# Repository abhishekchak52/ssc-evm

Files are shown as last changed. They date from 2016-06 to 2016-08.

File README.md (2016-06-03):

# ssc-evm
The Electronic Voting Machine for the St. Stephen's College Student's Union Society Elections for 2016-2017. With love from the Electronics Society

The basic design of the EVM is based on the Atmel ATmega328 chip which is at the heart of the Arduino UNO.
The final circuit will use only the chip instead of the entire Arduino board. The code is written in the Arduino language.

##TODO
* Make a working prototype using the Arduino UNO.
* Test for bugs.
* Port to a 40 AVR PDIP chip.

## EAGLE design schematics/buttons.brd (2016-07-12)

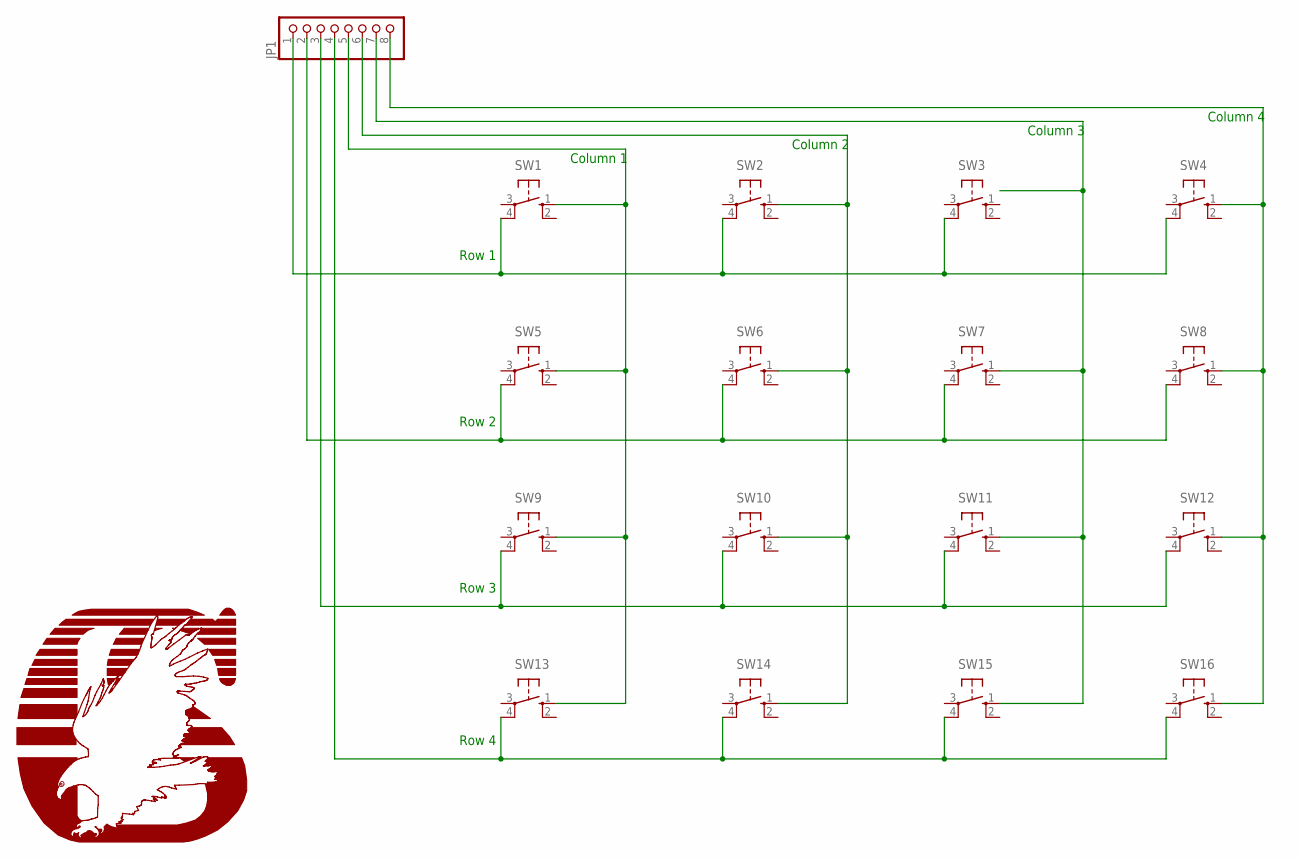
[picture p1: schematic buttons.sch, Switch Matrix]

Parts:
JP1: PINHD-1X8-3.5MM; 1X08-3.5MM
SW1, SW2, SW3, SW4, SW5, SW6, SW7, SW8, SW9, SW10, SW11, SW12, SW13, SW14, SW15, SW16: 10-XX; B3F-10XX

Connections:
unnamed: JP1.1, SW1.4 (P1), SW2.4 (P1), SW3.4 (P1), SW4.4 (P1)
unnamed: JP1.2, SW5.4 (P1), SW6.4 (P1), SW7.4 (P1), SW8.4 (P1)
unnamed: JP1.3, SW9.4 (P1), SW10.4 (P1), SW11.4 (P1), SW12.4 (P1)
unnamed: JP1.4, SW13.4 (P1), SW14.4 (P1), SW15.4 (P1), SW16.4 (P1)
unnamed: JP1.5, SW1.1 (S), SW5.1 (S), SW9.1 (S), SW13.1 (S)
unnamed: JP1.6, SW2.1 (S), SW6.1 (S), SW10.1 (S), SW14.1 (S)
unnamed: JP1.7, SW7.1 (S), SW11.1 (S), SW15.1 (S)
unnamed: JP1.8, SW4.1 (S), SW8.1 (S), SW12.1 (S), SW16.1 (S)

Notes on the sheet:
Row 1
Row 2
Row 3
Row 4
Column 1
Column 2
Column 3
Column 4

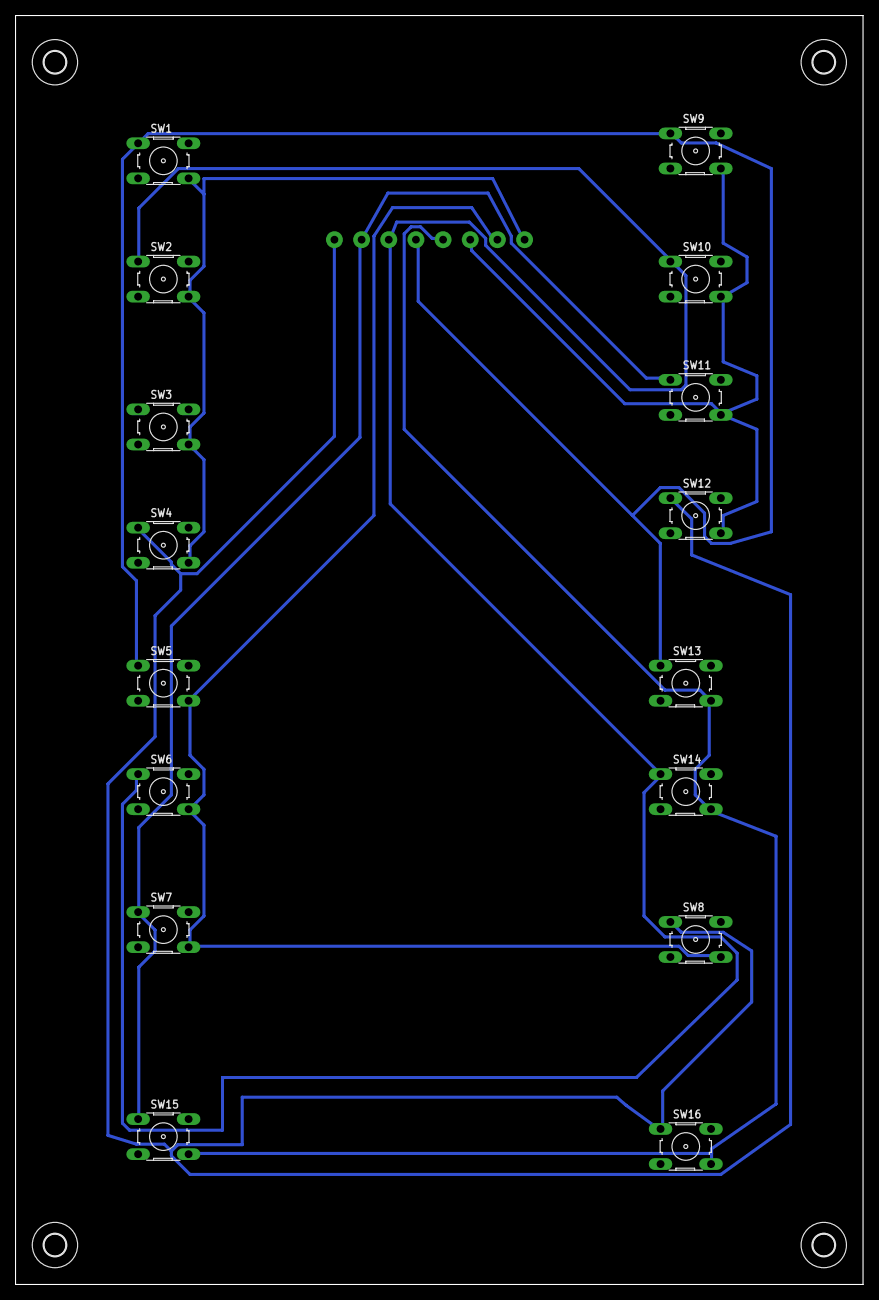
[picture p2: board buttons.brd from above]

Board: 2 copper layers, 109.2 x 163.5 mm, 21 parts (1 on the bottom side), 8 nets.

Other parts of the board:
U$1, U$2, U$3, U$4: 2,8

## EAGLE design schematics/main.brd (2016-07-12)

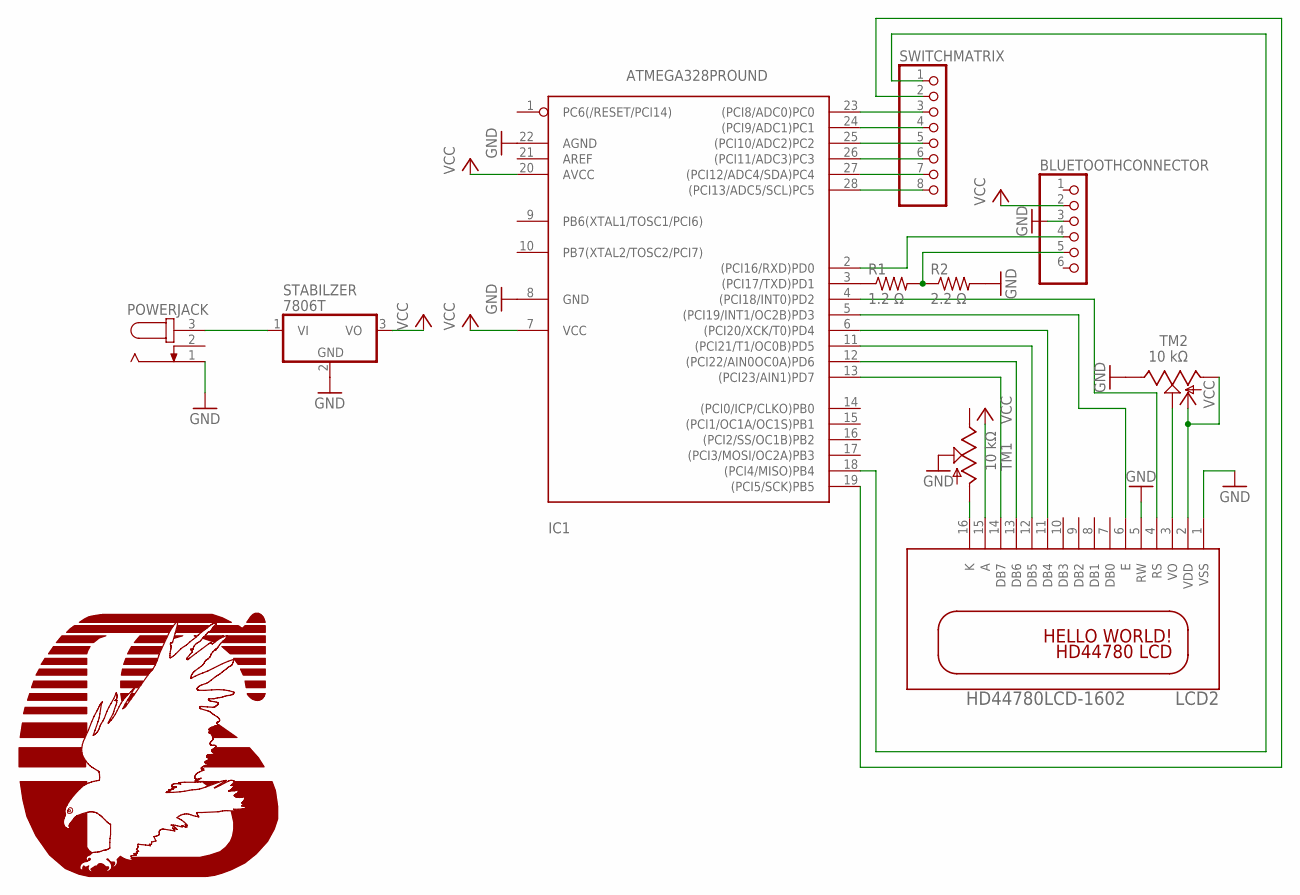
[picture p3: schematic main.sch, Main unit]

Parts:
BLUETOOTHCONNECTOR: PINHD-1X6B; 1X06-BIG
IC1: ATMEGA328PROUND; DIL28-3-ROUND
LCD2: HD44780LCD-1602; LCD1602
POWERJACK: JACK-PLUG0; SPC4077
R1: 1.2 Ω; 0207/10
R2: 2.2 Ω; 0207/10
STABILZER: 7806T; TO220H
SWITCHMATRIX: PINHD-1X8BIG; 1X08-BIG
TM1, TM2: 10 kΩ; 6MM

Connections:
GND: BLUETOOTHCONNECTOR.3, IC1.8 (GND), IC1.22 (AGND), LCD2.1 (VSS), LCD2.5 (RW), POWERJACK.1, R2.2, STABILZER.2 (GND), TM1.S, TM2.E
unnamed: BLUETOOTHCONNECTOR.4, IC1.2 ((PCI16/RXD)PD0)
unnamed: IC1.3 ((PCI17/TXD)PD1), R1.1
unnamed: BLUETOOTHCONNECTOR.5, R1.2, R2.1
unnamed: IC1.4 ((PCI18/INT0)PD2), LCD2.4 (RS)
unnamed: IC1.5 ((PCI19/INT1/OC2B)PD3), LCD2.6 (E)
unnamed: IC1.13 ((PCI23/AIN1)PD7), LCD2.14 (DB7)
unnamed: IC1.12 ((PCI22/AIN0OC0A)PD6), LCD2.13 (DB6)
unnamed: IC1.11 ((PCI21/T1/OC0B)PD5), LCD2.12 (DB5)
unnamed: LCD2.16 (K), TM1.A
unnamed: LCD2.3 (VO), TM2.S
unnamed: IC1.6 ((PCI20/XCK/T0)PD4), LCD2.11 (DB4)
unnamed: IC1.23 ((PCI8/ADC0)PC0), SWITCHMATRIX.3
unnamed: IC1.24 ((PCI9/ADC1)PC1), SWITCHMATRIX.4
unnamed: IC1.25 ((PCI10/ADC2)PC2), SWITCHMATRIX.5
unnamed: IC1.26 ((PCI11/ADC3)PC3), SWITCHMATRIX.6
unnamed: IC1.27 ((PCI12/ADC4/SDA)PC4), SWITCHMATRIX.7
unnamed: IC1.28 ((PCI13/ADC5/SCL)PC5), SWITCHMATRIX.8
unnamed: IC1.18 ((PCI4/MISO)PB4), SWITCHMATRIX.1
unnamed: IC1.19 ((PCI5/SCK)PB5), SWITCHMATRIX.2
unnamed: POWERJACK.3, STABILZER.1 (VI)
VCC: BLUETOOTHCONNECTOR.2, IC1.7 (VCC), IC1.20 (AVCC), LCD2.2 (VDD), LCD2.15 (A), STABILZER.3 (VO), TM2.A

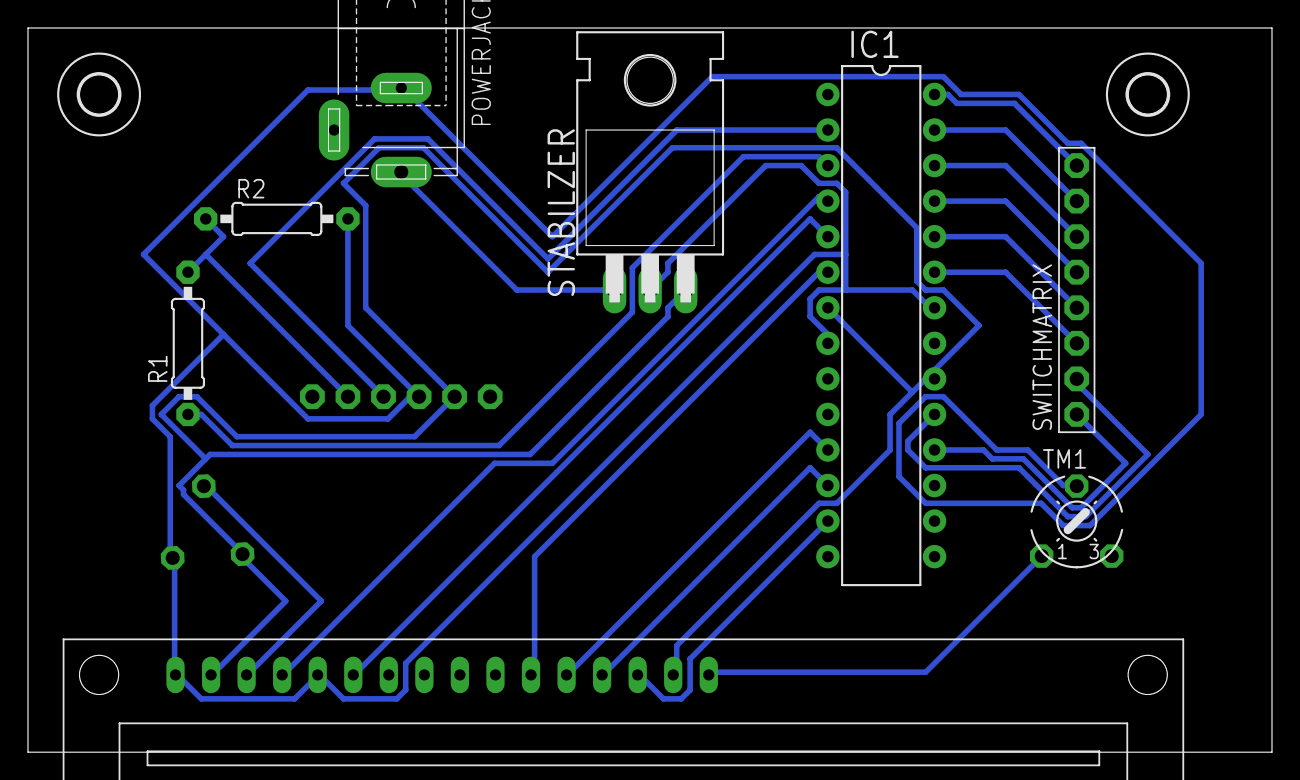
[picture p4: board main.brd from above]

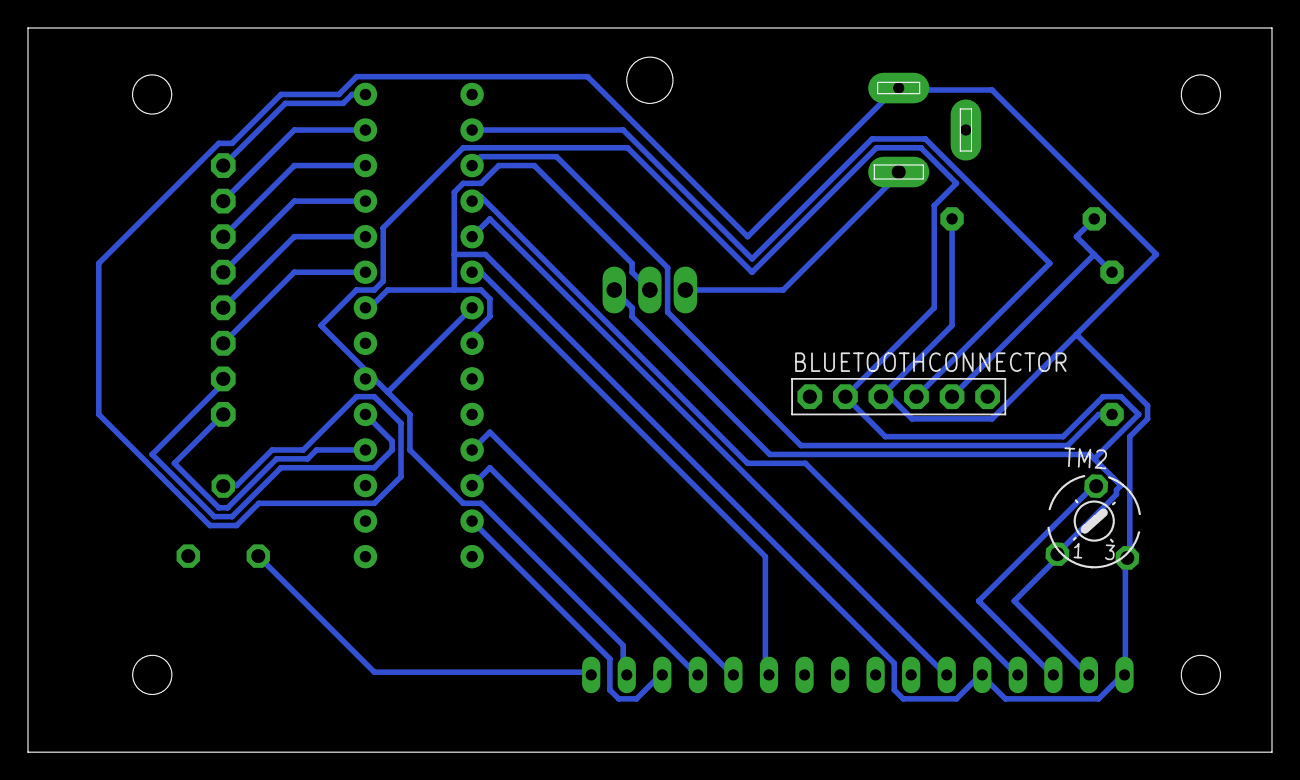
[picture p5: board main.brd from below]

Board: 2 copper layers, 88.9 x 51.7 mm, 12 parts (2 on the bottom side), 22 nets.

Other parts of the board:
U$1, U$2: 2,8

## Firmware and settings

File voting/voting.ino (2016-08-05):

#include <LiquidCrystal.h>
#include <Keypad.h>


const byte NUM_CANDIDATES = 4;
const byte LCD_RS = 2;
const byte LCD_E = 3;
const byte LCD_D4 = 4;
const byte LCD_D5 = 5;
const byte LCD_D6 = 6;
const byte LCD_D7 = 7;

const byte ROWS = 4; //four rows
const byte COLS = 4; //four columns
//define the cymbols on the buttons of the keypads
char hexaKeys[ROWS][COLS] = {
  {'1', '2', '3', 'A'},
  {'4', '5', '6', 'B'},
  {'7', '8', '9', 'C'},
  {'*', '0', '#', 'D'}
};
byte rowPins[ROWS] = {8, 9, 14, 15}; //connect to the row pinouts of the keypad
byte colPins[COLS] = {16, 17, 18, 19}; //connect to the column pinouts of the keypad

//initialize an instance of class NewKeypad
Keypad customKeypad = Keypad( makeKeymap(hexaKeys), rowPins, colPins, ROWS, COLS);
LiquidCrystal lcd(LCD_RS, LCD_E, LCD_D4, LCD_D5, LCD_D6, LCD_D7);
String vote;
void setup() {
  // put your setup code here, to run once:
  Serial.begin(9600);
  lcd.begin(16, 4);

}
char key;
char message[NUM_CANDIDATES];
int pref;

void loop()
{
  while (!Serial.find("enable")) {
    lcd.clear();
    lcd.print ("Wait for enable");

  }
  lcd.clear();
  lcd.print("Enabled");
  delay(1000);
  lcd.clear();

  // Vote for president

  lcd.print("President");
  delay(1000);
  pref = 1;
  while (pref <= NUM_CANDIDATES + 1) //Since pref starts at 1
  { 
    enter_again:
    if (pref != NUM_CANDIDATES + 1) {
      lcd.clear();
      lcd.print("#");
      lcd.print(pref);
      lcd.print(" preference");
      lcd.setCursor(0, 2);
      key = customKeypad.getKey();
      if (key)
      { 
        // Check if the character has been previously entered
        for (int i = 0; i < pref; i++) {
          if (key == message[i])
          {
            lcd.clear();
            lcd.setCursor(0,0);
            lcd.print("Invalid choice");
            lcd.setCursor(0, 1);
            lcd.print("Please choose");
            lcd.setCursor(0, 2);
            lcd.print("again.");
            delay(1500);
            goto enter_again; // Don't kill me.
          }
        }

        if (key == 'C')
        {
          for (int i = 0; i < NUM_CANDIDATES; i++)
            message[i] = '0';
          pref = 1;
          lcd.clear();
          continue;
        }
        else if (key == 'D')
        {
          for (; pref <= NUM_CANDIDATES; pref++)
            message[pref - 1] = 'n';
          continue;
        }
        message[pref - 1] = key;
        lcd.print(key);
        pref++;
        delay(1000);


      }
    }
    else if (pref == NUM_CANDIDATES + 1) //All votes for the ballot have been cast
    {
      lcd.setCursor(0, 0);
      for (int i = 0; i < NUM_CANDIDATES; i++) { // Show your preference
        lcd.print(i + 1);
        lcd.print(">");
        lcd.print(message[i]);
        lcd.print("|");
      }
      lcd.setCursor(0, 2); //Print confirm prompt
      lcd.print("C to cancel");
      lcd.setCursor(0, 3);
      lcd.print("D to confirm");
      key = customKeypad.getKey();
      if (key)
      {
        if (key == 'C')
        {
          for (int i = 0; i < NUM_CANDIDATES; i++)
            message[i] = '0'; //Reset the cote
          pref = 1; // Reset to preference 1
          lcd.clear();
          continue;
        }
        else if (key == 'D')
        {
          for (int i = 0; i < NUM_CANDIDATES; i++)
            Serial.print(message[i]);
          for (int i = 0; i < NUM_CANDIDATES; i++)
            message[i] = '0';
          break;
        }
        lcd.clear();
      }
    }
  }
  Serial.print("\n");
  delay(1000);
  lcd.clear();
}

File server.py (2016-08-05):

import serial
import time
import subprocess
import sys

bdaddr = "98:D3:31:90:71:B1"
port = "COM11"
baudrate = 9600


def server():
    """The server part of the script. Responsible for the actual communication during voting"""
    # Open the serial port
    while True:
        ser = serial.Serial(port, baudrate)
    # Print welcome message
        if raw_input("Send enable?(y/n)") == "y":
            ser.write("enable")
        else:
            sys.exit(0)

    # wait for data
        while True:
            if ser.in_waiting >= 4:
                print ser.read(4)
                break


def connect():
    """connect to the slave using the serial port"""
    subprocess.call(["sudo", "rfcomm", "-i", "hci0", "connect", port, bdaddr, "1"])


if __name__ == "__main__":
    if sys.argv[1] == "connect":
        connect()
    elif sys.argv[1] == "runserver":
        server()

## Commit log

2016-06-03 Created the Arduino branch of the project. This branch is the main area of development until the problems with the MegaCore problems are sorted out.
    [SD_test.ino]
2016-07-06 Added cancel vote functionality on 'C' key
    Pressing the 'C' button cancels your current input and restarts the ballot.
2016-07-12 Added Cadsoft Eagle schematics and PCB design files
    The main circuit and the buttons board each have two files: one .sch
    which is an eagle schematic and a .brd which is the PCB file
    [buttons.brd, buttons.sch, main.brd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]
2016-08-05 Added ballot format and error handling
    Error handling for the voting process.
    The procedure for the ballot is also included
    [server.py, voting.ino]
